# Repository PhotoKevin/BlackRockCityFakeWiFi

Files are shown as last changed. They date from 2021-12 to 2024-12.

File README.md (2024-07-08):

# BlackRockCityFakeWiFi

## Purpose
Create a joke WiFi access point for Black Rock City (aka Burning Man). The person trying to use the access point gets a huge list of Terms and Conditions in ever smaller font. Once they agree, they are run through some questions to "Prove they're not a robot".

Finally they get told that "Dorking around on the Internet" is against the principle of Immediacy and are dumped.

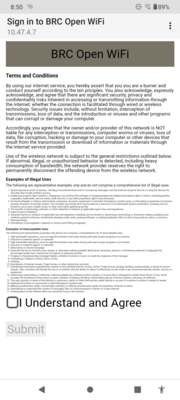
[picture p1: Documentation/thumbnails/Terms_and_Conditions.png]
Terms and Conditions
]
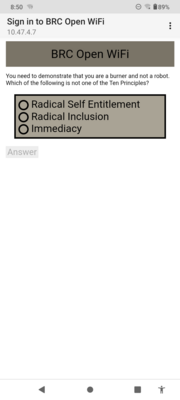
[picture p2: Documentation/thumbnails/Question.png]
Sample Question
]
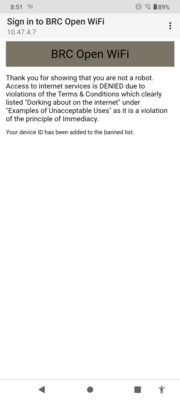
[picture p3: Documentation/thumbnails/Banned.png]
])

## Development Environment
I developed this on generic ESP8266 and ESP32 boards using the Arduino IDE. It also supports the OLED display on a Heltec WiFi Kit 32 (V3) or WiFi Kit 8. In addition to the OLED the Heltec boards are nice in that they can run off of either USB or a LiPo battery and can charge the battery from USB.

The web pages were created with the [Pulsar](https://pulsar-edit.dev) editor. A small C program is then used to convert the
pages into data stored in the main flash memory. The C program was developed in Visual Studio 2019.

Boards that I have tested on are:

- [Heltec WiFi Kit 32 (V3)](https://heltec.org/project/wifi-kit32-v3/)  
- [Heltec WiFi Kit 8](https://heltec.org/project/wifi-kit-8/)  
- [LOLIN (Wemos) D1 R1](https://www.wemos.cc/en/latest/d1/index.html)  
- [IdeaSpark ESP32](https://www.amazon.com/s?k=ideaspark)

## Captive Portal
The code implements a Captive Portal which operates like the typical free WiFi you'd find at a restaurant.
When the user connects it grabs all traffic from that user regardless of what they asked for and redirects it
to its signon process. I owe a lot to the [Mobile Rick Roll](https://github.com/idolpx/mobile-rr) project for their work in figuring out how to
implement this.

## Building the project
I'm using the Arduino 2.3.2 IDE.

- After installing the IDE go to the preferences (Control-Comma) and add these Additional Board Manager URLs.

- https://arduino.esp8266.com/stable/package_esp8266com_index.json  
- https://espressif.github.io/arduino-esp32/package_esp32_index.json
- https://github.com/Heltec-Aaron-Lee/WiFi_Kit_series/releases/download/3.0.0/package_heltec_esp32_index.json

- Exit and restart the IDE.

- In the Boards Manager (left column, second icon from the top) and install
    - "esp32 by Espressif Systems" version 3.0.1
    - "Arduino ESP32 Boards" version 2.0.13
    - "ESP8266 Boards" version 3.1.2

- Now go to the Library Manager (left column, third icon from the top) and install
    - ArduionJson by Benoit Blanchon. 7.0.4
    - ESP Async WebServer by me-no-dev 3.0.6
    - AsyncTCP by me-no-dev 3.1.4
    - ESPAsyncTCP by dvarrel 1.2.4
    - U8g2 by oliver. 2.34.22 - If using one of the boards with an OLED display.

- Plug your ESP board into a USB port.

- Click on the drop down in the button bar. Select your board and COM port.

- Lastly click on the Upload (right arrow) button to compile and install the software.

## Accessing the Status and Configuration Pages
- Bring up the list of access points and find BRC Open WiFi.
- Select that and you should be redirected to the giant page of legalese.
- Find the sentence "The following are representative examples only and do not comprise a comprehensive list of illegal</a> uses:"
- Click on the word "illegal".
- Log in with the default credentials of admin/changeme (both are all lower case).

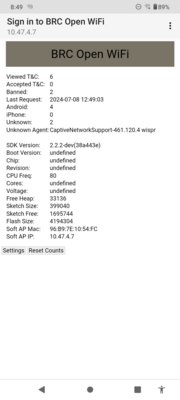
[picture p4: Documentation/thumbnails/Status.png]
]
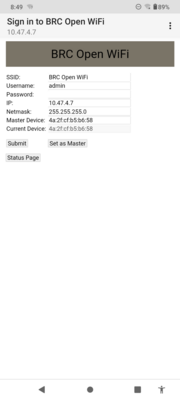
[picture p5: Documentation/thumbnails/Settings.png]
]

## Configuration Options
- SSID - Name of the Access Point that shows up on your phone.
- Username - Username for accessing the statistics and settings.
- Password - Password for same. If left blank the previous password will remain in effect.
- IP Address - The IP Address for the Access Point. Note: Changing this affects the address used to access the configuration page.
- Netmask - The Netmask for the Access Point. You almost certainly should not change this.
- Master Device - The MAC address of a master device (aka your phone) that will be automatically logged in and sent to the status page.
- Current Device - The MAC address of the device you're currently using. Displayed so you can copy it into the Master Device if you want.

Changing the settings will cause the ESP to reboot.

# Modifying the HTML pages

The html directory contains all of the HTML, CSS, JavaScript, etc. It has to be converted into
a cpp file with strings. This can be done with the HtmlHelper program. You have to build the HtmlHelper with Visual Studio, or some other C compiler. Then run it as follows to put it into a C file

> HtmlHelper.exe --output=webpages.cpp --include=BMWiFi.h blocked.html brc.css checkbox.css legal.html question.html questions.js questions.json debugdata.js radio2.css banned.html banned.js redirect.html status.html status.js bmwifi.js settings.html settings.js login.html

Move the resulting webpages.cpp file over to the BMWiFi directory.
> move *.cpp ..\BMWiFi

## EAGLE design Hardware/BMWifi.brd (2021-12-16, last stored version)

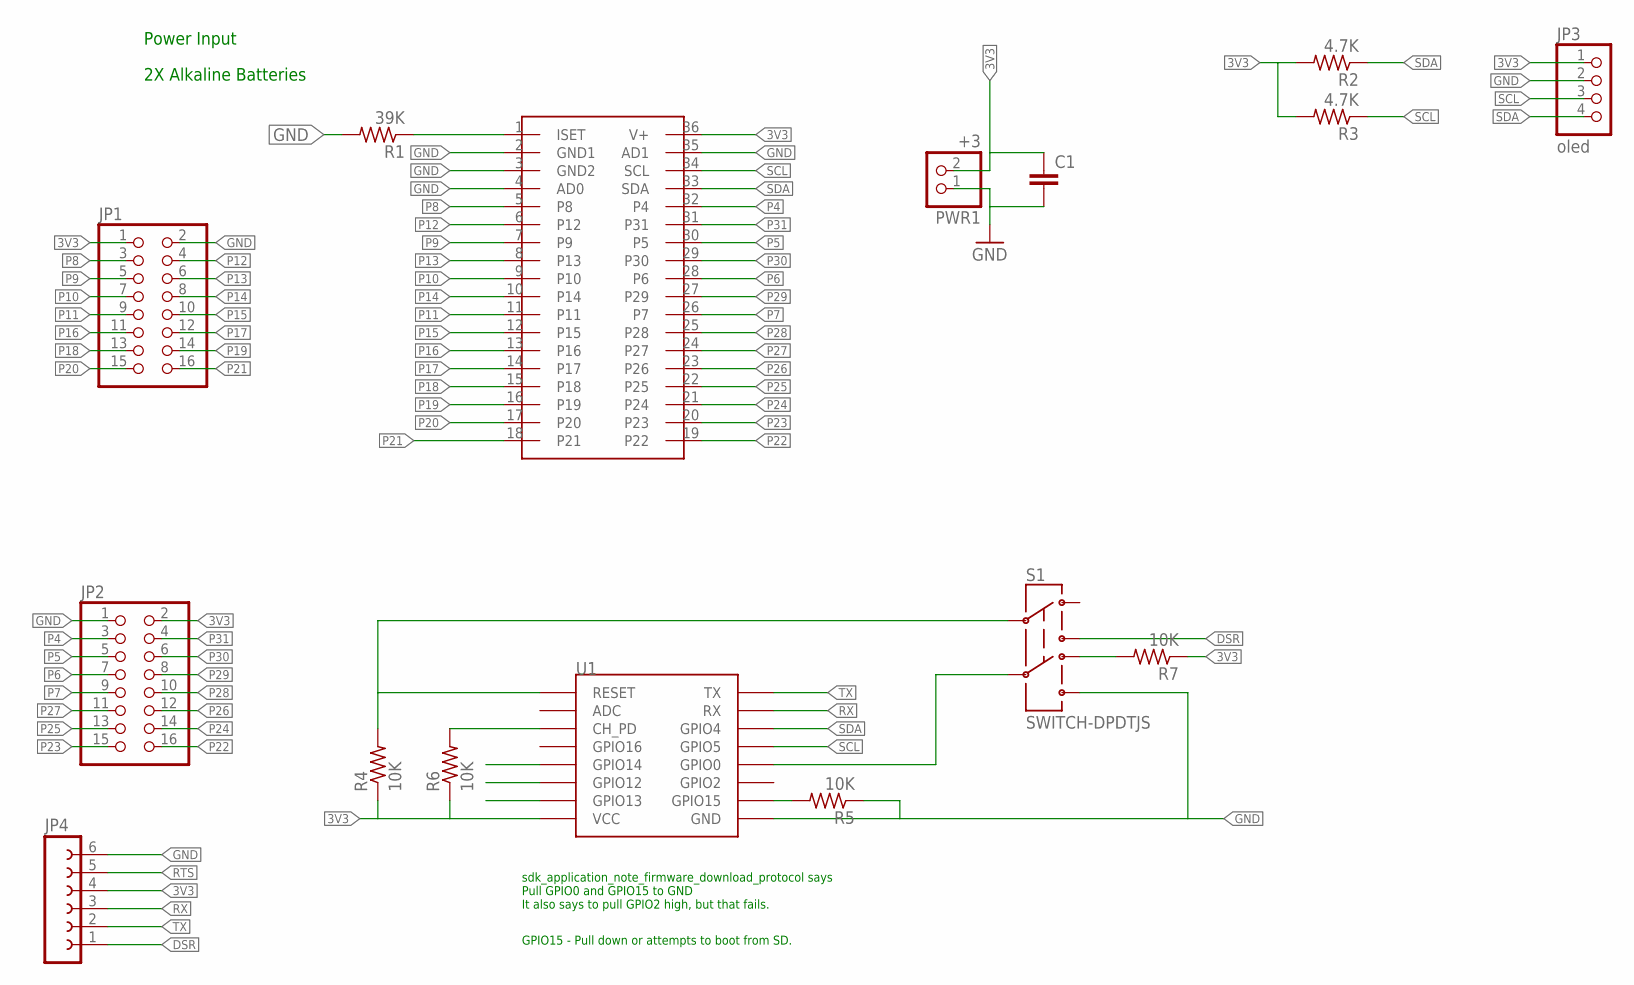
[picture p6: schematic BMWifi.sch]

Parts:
C1: C2.5/2; C2.5-2
JP1, JP2: PINHD-2X8; 2X08
JP3: oled; 1X04
JP4: FE06W
PWR1: +3; 1X02
R1: 39K; M1206
R2, R3: 4.7K; M1206
R4, R5, R6, R7: 10K; M1206
S1: SWITCH-DPDTJS; JS202011CQN
U1: ESP12
U$1: MAX6956; SSOP36

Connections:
3V3: C1.1, JP1.1, JP2.2, JP3.1, JP4.4, PWR1.2, R2.2, R3.2, R4.1, R6.1, R7.1, U1.VCC, U$1.36 (V+)
CH_PD: R6.2, U1.CH_PD
DSR: JP4.1, S1.3
GND: C1.2, JP1.2, JP2.1, JP3.2, JP4.6, PWR1.1, R1.2, R5.1, S1.6, U1.GND, U$1.2 (GND1), U$1.3 (GND2), U$1.4 (AD0), U$1.35 (AD1)
GPIO0: S1.5, U1.GPIO0
GPIO14: U1.GPIO14
GPIO15: R5.2, U1.GPIO15
ISET: R1.1, U$1.1 (ISET)
unnamed: R7.2, S1.4
P4: JP2.3, U$1.32 (P4)
P5: JP2.5, U$1.30 (P5)
P6: JP2.7, U$1.28 (P6)
P7: JP2.9, U$1.26 (P7)
P8: JP1.3, U$1.5 (P8)
P9: JP1.5, U$1.7 (P9)
P10: JP1.7, U$1.9 (P10)
P11: JP1.9, U$1.11
P12: JP1.4, U$1.6 (P12)
P13: JP1.6, U$1.8 (P13)
P14: JP1.8, U$1.10 (P14)
P15: JP1.10, U$1.12 (P15)
P16: JP1.11, U$1.13 (P16)
P17: JP1.12, U$1.14 (P17)
P18: JP1.13, U$1.15 (P18)
P19: JP1.14, U$1.16 (P19)
P20: JP1.15, U$1.17 (P20)
P21: JP1.16, U$1.18 (P21)
P22: JP2.16, U$1.19 (P22)
P23: JP2.15, U$1.20 (P23)
P24: JP2.14, U$1.21 (P24)
P25: JP2.13, U$1.22 (P25)
P26: JP2.12, U$1.23 (P26)
P27: JP2.11, U$1.24 (P27)
P28: JP2.10, U$1.25 (P28)
P29: JP2.8, U$1.27 (P29)
P30: JP2.6, U$1.29 (P30)
P31: JP2.4, U$1.31
RESET: R4.2, S1.2, U1.RESET
RTS: JP4.5
RX: JP4.3, U1.RX
SCL: JP3.3, R3.1, U1.GPIO5, U$1.34 (SCL)
SDA: JP3.4, R2.1, U1.GPIO4, U$1.33 (SDA)
TX: JP4.2, U1.TX

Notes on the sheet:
Power Input
2X Alkaline Batteries
GPIO15 - Pull down or attempts to boot from SD.
sdk_application_note_firmware_download_protocol says Pull GPIO0 and GPIO15 to GND It also says to pull GPIO2 high, but that fails.

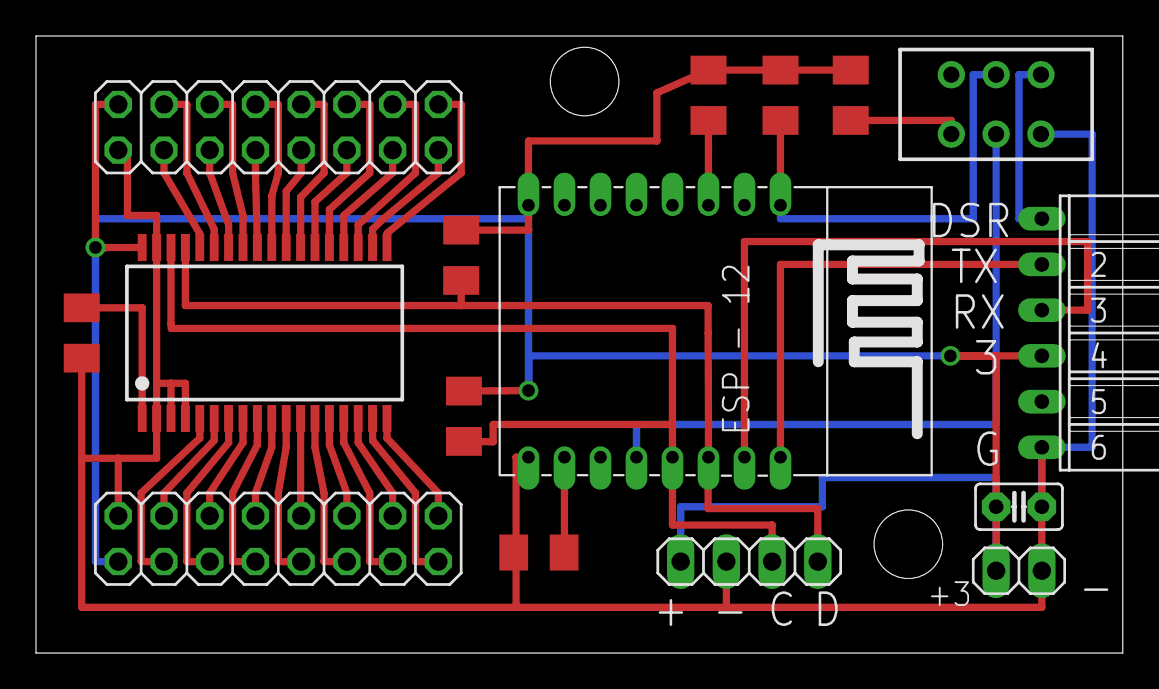
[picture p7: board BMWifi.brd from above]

Board: 2 copper layers, 60.4 x 34.3 mm, 16 parts (0 on the bottom side), 41 nets.

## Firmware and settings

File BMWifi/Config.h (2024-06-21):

// Name that shows up as available access points
#define DEFAULT_SSID  "BRC Open WiFi"
#define DEFAULT_ADMIN      "admin"
#define DEFAULT_PASSWORD   "changeme"
#define DEFAULT_MASTER {0x4A,0x2F,0xCF,0xB5,0xB6,0x58}

// Name of device on network. 
#define DEFAULT_HOSTNAME "BRCWiFi"


#define DEFAULT_IPADDRESS  {10,47,4,7}
#define DEFAULT_NETMASK    {255,255,255,0}

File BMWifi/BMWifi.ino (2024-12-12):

//#define NOT_AP    // Define for debugging as just a device on the network

//#define IDEA_SPARK // Define for IdeaSpark boards. Needed since they don't have their own board type.

#if defined (ARDUINO_wifi_kit_8) || defined (IDEA_SPARK) || defined (ARDUINO_HELTEC_WIFI_KIT_32_V3) || defined (ARDUINO_HELTEC_WIFI_KIT_32)
   #define USE_LCD_DISPLAY
   // #define USE_U8G2 // Define if you want to use the G2 version of the libraries. Pointless really. 
#endif

#include <DNSServer.h>
#include <Wire.h>
#include <EEPROM.h>
#include <Ticker.h>
#if defined (ESP32)
   #include <esp_wifi.h>
   #include <WiFi.h>
   #include <ESPmDNS.h>
   #include <ESPAsyncWebServer.h>
#elif defined (ESP8266)

   #include "ets_sys.h"
   #include <ESP8266WiFi.h>
   #include <ESP8266mDNS.h>
   #include <ESPAsyncTCP.h>
   #include <ESPAsyncWebServer.h>
#else
   #error Change your board type to an ESP32
#endif

char lastPageReq[512];

#include "Config.h"

// https://github.com/olikraus/u8g2
#if defined (USE_LCD_DISPLAY)
   #if defined (USE_U8G2)
      #include <U8g2lib.h>
   #else
      #include <U8x8lib.h>
   #endif

   #if defined (ARDUINO_wifi_kit_8)
      // Heltec WiFi Kit 8
      #if defined (USE_U8G2)
         U8G2_SSD1306_128X32_UNIVISION_F_HW_I2C u8x8(U8G2_R0, /* reset=*/ 16, U8X8_PIN_NONE, U8X8_PIN_NONE);
      #else
         U8X8_SSD1306_128X32_UNIVISION_HW_I2C u8x8(/* reset=*/ 16);
      #endif

   #elif defined (ARDUINO_HELTEC_WIFI_KIT_32_V3)
      U8X8_SSD1306_128X64_NONAME_SW_I2C u8x8(/* clock=*/ 18, /* data=*/ 17, /* reset=*/ 21);

   #elif defined (ARDUINO_HELTEC_WIFI_KIT_32)
      U8X8_SSD1306_128X64_NONAME_SW_I2C u8x8(/* clock=*/ 15, /* data=*/ 4, /* reset=*/ 16);

   #elif defined (IDEA_SPARK)
      #if defined (U8G2LIB_HH)
         U8G2_SSD1306_128X64_NONAME_F_SW_I2C u8x8 (U8G2_R0, 22, 21, U8X8_PIN_NONE);
         #define drawString drawStr
      #else
         U8X8_SSD1306_128X64_NONAME_SW_I2C u8x8 (22, 21, U8X8_PIN_NONE);
      #endif
   #endif

#endif

//https://android.googlesource.com/platform/frameworks/base/+/c80f952/core/java/android/net/CaptivePortalTracker.java
#include "BMWifi.h"

// You need to supply your own Secret.h defining 
//#define NETWORK_SSID "<SSID>"      
//#define NETWORK_PASS "<password>"  
#if defined (NOT_AP)
   #include "Secret.h"
#endif

bool clockSet = false;

IPAddress apIP(10,47,4,7);
IPAddress netMsk(255,255,255,0);

AsyncWebServer server(80);
AsyncEventSource events("/events");

const byte DNS_PORT = 53;

DNSServer dnsServer;

struct eeprom_data_t  EEData;
int EEChanged = 0;
int RestartRequired = 0;

#if defined (NOT_AP)
   void  ConnectToNetwork (void);
#else
   void  SetupAP (void);
#endif

//ADC_MODE(ADC_VCC);      // Needed to make the ESP.getVCC function work.

//#include "heltec.h"
void setup (void)
{
   RestartRequired = 0;
//   Serial.begin (9600);                           // full speed to monitor
   Serial.begin (115200);                           // full speed to monitor
   delay(2000);
   Serial.println ("\n\n\n");
   Serial.println (ARDUINO_BOARD);

   memset (lastPageReq, 0, sizeof lastPageReq);
   #if defined (USE_LCD_DISPLAY)
      Serial.println ("Setting up LCD");
      u8x8.begin();
      u8x8.setPowerSave (0);
      #if defined (U8G2LIB_HH)
         u8x8.setFont (u8g2_font_chroma48medium8_8r);
      #else
         u8x8.setFont (u8x8_font_chroma48medium8_r);
      #endif
   #endif
   Serial.print ("\nBMWifi Starting\n");

   EEPROM.begin (sizeof EEData); 
   ReadEEData (EEDataAddr, &EEData, sizeof EEData);
   if (EEData.eepromDataSize != sizeof EEData)
   {
      Serial.println ("Setting default EEData values");
      uint8_t *macaddr = getMacAddress ();
      uint8_t lastMacOctet = macaddr[5];
      if (lastMacOctet == 0)
         lastMacOctet = 1;

      uint8_t ip[] = DEFAULT_IPADDRESS;
      uint8_t mask[] = DEFAULT_NETMASK;
      uint8_t master[] = DEFAULT_MASTER;
      memset (&EEData, 0, sizeof EEData);
      EEData.eepromDataSize = sizeof EEData;
      str_copy (EEData.username, DEFAULT_ADMIN, sizeof EEData.username);
      str_copy (EEData.password, DEFAULT_PASSWORD, sizeof EEData.password);
      EEData.displayTimeoutSeconds = 90;

      snprintf (EEData.SSID, sizeof EEData.SSID, "%s %d", DEFAULT_SSID, lastMacOctet);
      snprintf (EEData.hostname, sizeof EEData.hostname, "%s %d", DEFAULT_HOSTNAME, lastMacOctet);
      ip[3] = lastMacOctet % 0x7f;

      for (int i=0; i<4; i++)
      {
         EEData.ipAddress[i] = ip[i];
         EEData.netmask[i] = mask[i];
      }

      for (int i=0; i<6; i++)
         EEData.masterDevice[i] = master[i];
      EEChanged = 1;
   }

   #if defined (NOT_AP)
      ConnectToNetwork ();
   #else
      SetupAP ();
   #endif

   Serial.print ("SDK Version: ");
   Serial.println (ESP.getSdkVersion());
   Serial.println (getSystemInformation ());

#if !defined (NOT_AP)

   // Setup MDNS responder
   Serial.println (EEData.hostname);
   if (!MDNS.begin (EEData.hostname)) 
      Serial.println("Error setting up MDNS responder!");
   else 
   {
      Serial.printf ("mDNS responder started: %s\n", EEData.hostname);
      // Add service to MDNS-SD
      MDNS.addService ("http", "tcp", 80);
//      MDNS.addService ("https", "tcp", 443);
   }
#endif

   setupWebServer ();

}


/// Setup the ESP32 as an Access Point

void SetupAP (void)
{
//   WiFi.disconnect (true, true);
   WiFi.mode (WIFI_AP);

   apIP = IPAddress (EEData.ipAddress);
//   netMsk = IPAddress (EEData.netmask);

   WiFi.softAPConfig (apIP, apIP, netMsk);
   WiFi.softAP (EEData.SSID); // No password, this is an open access point

   Serial.print ("AP is ");
   Serial.println (WiFi.softAPIP ().toString());

   // Set up a DNS server. 
   dnsServer.setErrorReplyCode (DNSReplyCode::NoError);

   dnsServer.setTTL(0);
   dnsServer.start (DNS_PORT, "*", WiFi.softAPIP ());
}

/// Connect the ESP to a network
/// This is really for debugging, it's a lot
/// easier to do most of the testing from a
/// desktop webbrowser with developer tools
/// than it is to work on a phone.
/// You need to define your user/pw in Secret.h
/// as included above

#if defined (NOT_AP)
void ConnectToNetwork (void)
{
   Serial.print ("Connecting");
   WiFi.disconnect ();
   WiFi.mode (WIFI_STA);

   wl_status_t ws = WiFi.begin (NETWORK_SSID, NETWORK_PASS); // Connect to WiFi network
   Serial.printf ("\nWiFi.Begin: %d\n", ws);

   // Wait until we connect, and do some status messages
   while (WiFi.localIP()[0] == 0)
   {
      char stat[20];
   
      Serial.print (".");
      sprintf (stat, "%d\n", WiFi.status ());
      Serial.print (stat);
      delay (1000);
   }

   Serial.print ("localIP: ");
   Serial.println (WiFi.localIP());
}
#endif

boolean connectRequired;
unsigned long lastConnectTry = 0;
int laststatus = WL_IDLE_STATUS;

#if defined (USE_LCD_DISPLAY)
// Pad a string with blanks.
// This is used to clear to end-of-line on the OLE display
static void pad (char *str, size_t strsize)
{
   char *p = str + strlen (str);
   while ((size_t) (p - str) < strsize-1)
   {
      *p++ = ' ';
      *p = '\0';
   }
}
#endif


void drawString (int x, int y, const char *s)
{
   #if defined (U8G2LIB_HH)
      u8x8.drawStr (8*x+8, 8*y+8, s);
//      u8x8.sendBuffer ();
   #elif defined (U8X8LIB_HH)
      u8x8.drawString (x, y, s);
   #endif
}

// The OLED is 4 rows of 16 characters.
// 0123456789012345
// BRC WiFi
// Red xxx Ban xxx
// Batt xxxx
// 22-01-01 12:00

char prevLastPageReq[512];
void DisplayOLEDStatus (void)
{
   static time_t lastDisplayUpdate = 0;
   static time_t prevActivity = 0;
   static int prevRedirects = -1;
   static int prevBanned = -1;

   // Work out if we need to refresh the display. Do it as a batch so the serial output is all or nothing
   if (prevRedirects != EEData.legalShown || prevBanned != EEData.totalBanned || prevActivity != EEData.lastActivity)
   {
      #if defined (U8G2LIB_HH)
         u8x8.setPowerSave (0);
      #endif
      (void) time (&lastDisplayUpdate);
      prevRedirects = EEData.legalShown;
      prevBanned = EEData.totalBanned;
      prevActivity = EEData.lastActivity;

      char buffer[17];
      #if defined (USE_LCD_DISPLAY)
         drawString (0, 0, EEData.hostname);
      #endif
     
      snprintf (buffer, sizeof buffer, "Red %-3d Ban %-3d ", EEData.legalShown, EEData.totalBanned);
      Serial.println (buffer);
      yield ();
      #if defined (USE_LCD_DISPLAY)
         pad (buffer, sizeof buffer);
         drawString (0, 1, buffer);
      #endif

      strftime (buffer, sizeof buffer, "%y-%m-%d %H:%M", gmtime (&EEData.lastActivity));
      Serial.println (buffer);
      yield ();
      #if defined (USE_LCD_DISPLAY)
         pad (buffer, sizeof buffer);
         drawString (0, 3, buffer);
         #if defined (U8G2LIB_HH)
            u8x8.sendBuffer ();
            Serial.println ("sendBuffer");
         #endif
      #endif
   }

   if (strncmp (lastPageReq, prevLastPageReq, sizeof prevLastPageReq) != 0)
   {
      str_copy (prevLastPageReq, lastPageReq, sizeof prevLastPageReq);
      Serial.print ("Last Page Requested: ");
      Serial.println (lastPageReq);
      yield ();
   }

   #if defined (USE_LCD_DISPLAY)
      u8x8.refreshDisplay();    // only required for SSD1606/7  

      time_t now = time (NULL);
      if ((EEData.displayTimeoutSeconds > 0) && difftime (now, lastDisplayUpdate) > EEData.displayTimeoutSeconds)
         u8x8.setPowerSave (1);
   #endif
}

void loop (void)
{
//   static unsigned long prevHeap = 4000000;
   DisplayOLEDStatus ();
   SaveEEDataIfNeeded (EEDataAddr, &EEData, sizeof EEData);

   if (RestartRequired)
   {
      if (EEChanged)
         WriteEEData (EEDataAddr, &EEData, sizeof EEData);

      ESP.restart ();
      while (1)
         ;
   }
   yield ();

   #if defined (NOT_AP)
      if (connectRequired) 
      {
         Serial.println ( "Connect requested" );
         connectRequired = false;
         ConnectToNetwork ();
         lastConnectTry = millis();
         yield ();
      }
   #endif

   int currentStatus = WiFi.status();
   if ((currentStatus == 0) && (millis() > (lastConnectTry + 60000))) 
   {
      /* If WLAN disconnected and idle try to connect */
      /* Don't set retry time too low as retry interfere the softAP operation */
      connectRequired = true;
   }

   yield ();
  
   if (laststatus != currentStatus) 
   {
      // WLAN status change
      Serial.print ("Status: ");
      Serial.println (WiFiStatus (currentStatus));
      yield ();
      laststatus = currentStatus;
      if (currentStatus == WL_CONNECTED) 
      {
         /* Just connected to WLAN */
         Serial.println ( "" );
         Serial.print ("IP address: ");
         Serial.println (WiFi.localIP());
         yield ();
      }
      else if (currentStatus == WL_NO_SSID_AVAIL) 
      {
        WiFi.disconnect();
      }
   }

   dnsServer.processNextRequest();
}

/// Convert a WiFi Status to a human readable string
/// Codes defined in wl_definitions.h
String  WiFiStatus (int s)
{
   switch (s)
   {
   case WL_NO_SHIELD:  return "No Shield";              // 255
   case WL_IDLE_STATUS: return "Idle";                  // 0
   case WL_NO_SSID_AVAIL: return "No SSID Available";   // 1
   case WL_SCAN_COMPLETED: return "Completed";          // 2
   case WL_CONNECTED: return "Connected";               // 3
   case WL_CONNECT_FAILED: return "Connect Failed";     // 4
   case WL_CONNECTION_LOST: return "Connection Lost";   // 5
   #if defined (ESP8266)
      case WL_WRONG_PASSWORD: return "Wrong Password";     // 6
   #else
      case WL_STOPPED: return "Stopped";                   // 254
   #endif
   case WL_DISCONNECTED: return "Disconnected";         // 7
   default: return "Unknown status";                    //
   }
}

uint8_t *getMacAddress ()
{
   static uint8_t _macAddress[6];
   #if defined (ESP8266)
      wifi_get_macaddr (STATION_IF, _macAddress);
   #elif defined (ESP32)

      wifi_init_config_t cfg = WIFI_INIT_CONFIG_DEFAULT ();
      esp_wifi_init (&cfg);
      esp_err_t rc = esp_wifi_get_mac (WIFI_IF_STA, _macAddress);
      esp_wifi_deinit ();
      Serial.printf ("rc = %x\n", rc);
   #else
      memset (_macAddress, 0, sizeof _macAddress);
   #endif
   Serial.printf ("%02x:%02x:%02x:%02x:%02x:%02x\n", _macAddress[0], _macAddress[1], _macAddress[2], _macAddress[3], _macAddress[4], _macAddress[5]);

   return _macAddress;
}

static char localIPAddress[4*3+3+1] = "";
const char *localIP (void)
{
   if (localIPAddress[0] =='\0')
   {
      #if defined (NOT_AP)
         str_copy (localIPAddress, WiFi.localIP().toString().c_str(), sizeof localIPAddress);
      #else
         str_copy (localIPAddress, WiFi.softAPIP().toString().c_str(), sizeof localIPAddress);
      #endif
   }

   return localIPAddress;   
}

/// Copy the src string to the destination and insert a 
/// trailing null if needed.
void str_copy (char *dest, const char *src, size_t len)
{
   strncpy (dest, src, len);
   dest[len-1] = '\0';
}

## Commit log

2021-12-16 Convert to be AJAX. Most web functionality is in place.
    [BMWifi.brd, BMWifi.sch]
2021-12-21 Fixed all of the html/css issues and have the pages looking decent.
    [BMWifi.ino, WebServer.cpp]
2022-06-06 Display the voltage number
2022-06-06 Remove the hardware tree.
    I don't know why I thought I needed this when I started. Maybe an accident of copying from an old project.
    [BMWifi.brd, BMWifi.sch]
2022-08-05 Change from ESP8266 to ESP32
    Converted from ESP8266 to ESP32 so I could get https. This involved an entire new set of API calls.
2022-08-22 Probably what I'll take to BRC.
    Still didn't work on Greg's Android 12 phone.
    Removed cookie.
    Added a login link
    Cleaned up a lot of logging
    Proper reboot on settings change.
    [BMWifi.ino, Security.cpp, WebServer.cpp]
2023-06-03 When through a connection sequence correctly on my old phone.
    [BMWifi.ino, Security.cpp, WebServer.cpp]
2023-06-06 Ripped out https support. It was a mistake to add it.
    [BMWifi.ino, Security.cpp, WebServer.cpp]
2023-06-08 Changed to a different web server library that works on both ESP8266 and ESP32 chips.
2024-06-21 Updated Arduino to 2.3.2 and other libraries.
2024-06-21 Strip out Dhcp mistake
    [BMWifi.ino, Config.h]
2024-06-22 Time display was wrong.
    [BMWifi.ino]
2024-07-04 Support IdeaSpark boards. Support U8G2 for no reason.
2024-07-07 Removed support for old Heltec ESP32. Not supported by current libraries.
2024-07-09 Have the defaults use the final octet of the mac.
    This change means you can make a bunch of access points and not have them colliding with each other.
    [BMWifi.ino]
2024-12-12 Fixed bug with timestamp. Added some logging. Beginnings of display timeout.
    [BMWifi.ino, WebServer.cpp]

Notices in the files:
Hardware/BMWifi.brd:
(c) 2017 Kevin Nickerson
